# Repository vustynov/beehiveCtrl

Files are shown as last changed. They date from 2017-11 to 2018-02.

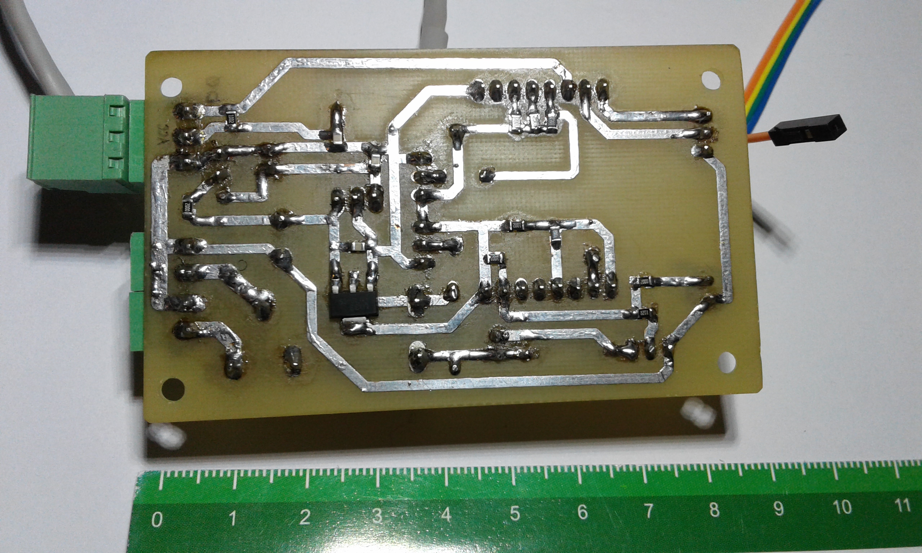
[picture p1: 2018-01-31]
board/BeeTermostat-appearance-bottom.jpg

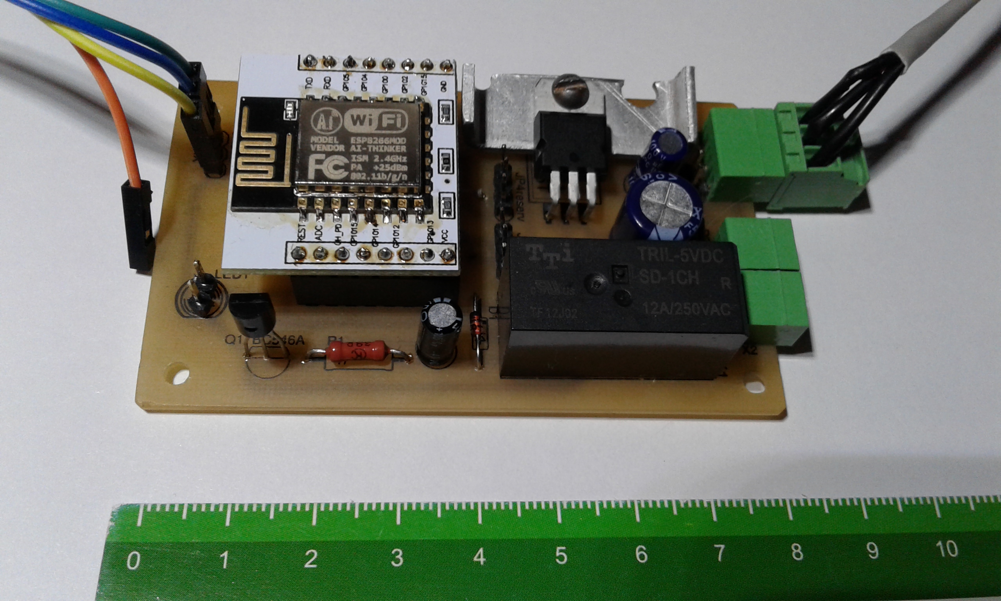
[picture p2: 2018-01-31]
board/BeeTermostat-appearance-top.jpg

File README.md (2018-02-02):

# beehiveCtrl

### Brief
This project can be interesting for amateur beekeeping. The project is designed to monitor the temperature and control the heating of beehives remotely. The device and software can also be used to control temperature control in other projects, such as an incubator.

The device is based on the microcontroller [ESP8266](http://www.esp8266.com) and firmware [NodeMCU](https://en.wikipedia.org/wiki/NodeMCU).

### Features
 * Remote control the temperature in the hive via browser on your computer, smartphone, tablets
 * Remote set the parameters of heater (minimal and maximal temperature)
 * Transfer of the temperature and the current status of the heater to the [thingspeak.com](http://thingspeak.com) every X minutes
 * Builds the [charts](https://thingspeak.com/channels/185299)
 * Once set up, the device can work offline, without internet connection.

### Schems and Circuit board
Directory **board** contains schematic and circuit board of device developed in [EAGLE](https://www.autodesk.com/products/eagle/overview). 
The scheme is very simple. It consists the power regulatots (LM7805 and 1117S33) for the relay coil and microcontroller. To switch on the relay a driver is used the BC546 transistor.

### Source code
Directory **src** contains the source code of the project, wroted on Lua and based on [NodeMCU API](https://nodemcu.readthedocs.io/en/master/).

### How to build
1. Build the board according to the schematic diagram showed on **board/BeeTermostat.sch**
2. Connect *+12-18V* power to *X1* connector on your board without installing the ESP8266 and check the correctness of the voltage at the points of the circuit where the power of the microcontroller must be approached. It should be the "3.3V".
3. Power off your board, install the ESP8266 to the socket on the board, and connect the **JP3** (TX,RX,GND) connector to the computer via USB-TTL adapter. For example, you can use [this device](http://www.instructables.com/id/USB-to-TTL-Converter-PL2303HX/) for that.
4. Power on your board and check the WiFi new access points in you environment. You should discover a new access point with a default name (installed by [Expressif](https://www.espressif.com/) ).
5. Build and download the NodeMCU firmware from the [nodemcu-build.com](https://nodemcu-build.com/) Choose the following modules:
 - DS18B20
 - file
 - GPIO
 - net
 - node
 - 1-wire
 - timer
 - UART
 - WiFi
 - float

6. Install the NodeMCU firmware to microcontroller. Under Linux you can use the [esptool](https://github.com/espressif/esptool) (read this [esp-linux-guide](http://www.whatimade.today/flashing-the-nodemcu-firmware-on-the-esp8266-linux-guide/) for that. Example of install:
```
$ sudo ./esptool-master/esptool.py --port /dev/ttyUSB0 --baud 460800 write_flash --flash_size 32m -fm dio 0x00000 ./nodemcu-master-10-modules-2017-09-25-18-22-58-float.bin
```

7. Install the [ESPlorer](https://esp8266.ru/esplorer/) or some another tools for working with NodeMCU to your computer.
8. Upload the lua scripts from directory **src** to your ESP microcontoller by using the ESPlorer or some another tools.
9. Restart module, find new WiFi access point *beehive* and try to connect to this AP with password *11111111*. You can change *SID* and *password* before in the **src/bc-init.cfg**.
10. If connect is successfull, try to open http://192.168.2.1 in your browser. You sould see the page with configuration of your beehive controller.
11. Try to change the temperature settings and check your heater.

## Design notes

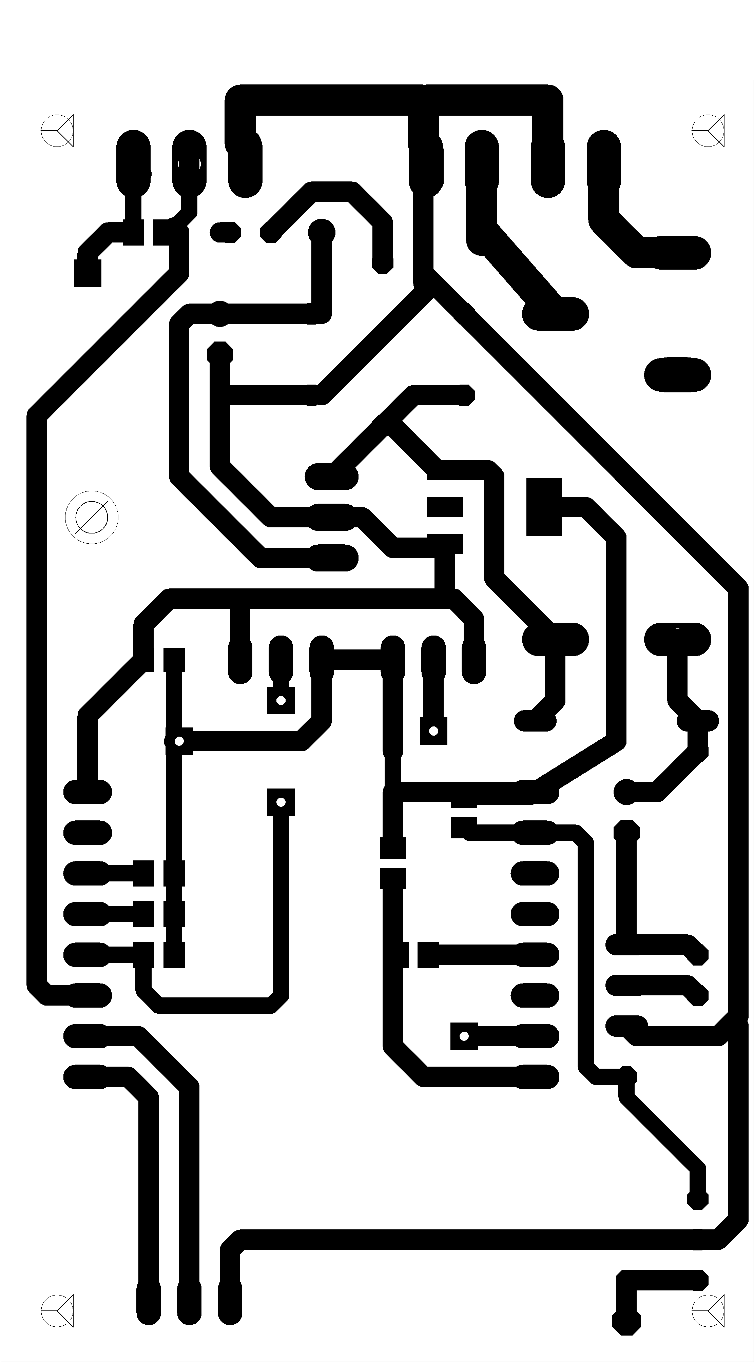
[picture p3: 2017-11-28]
board/beehiveTermostat_bottom_pcb_i.png

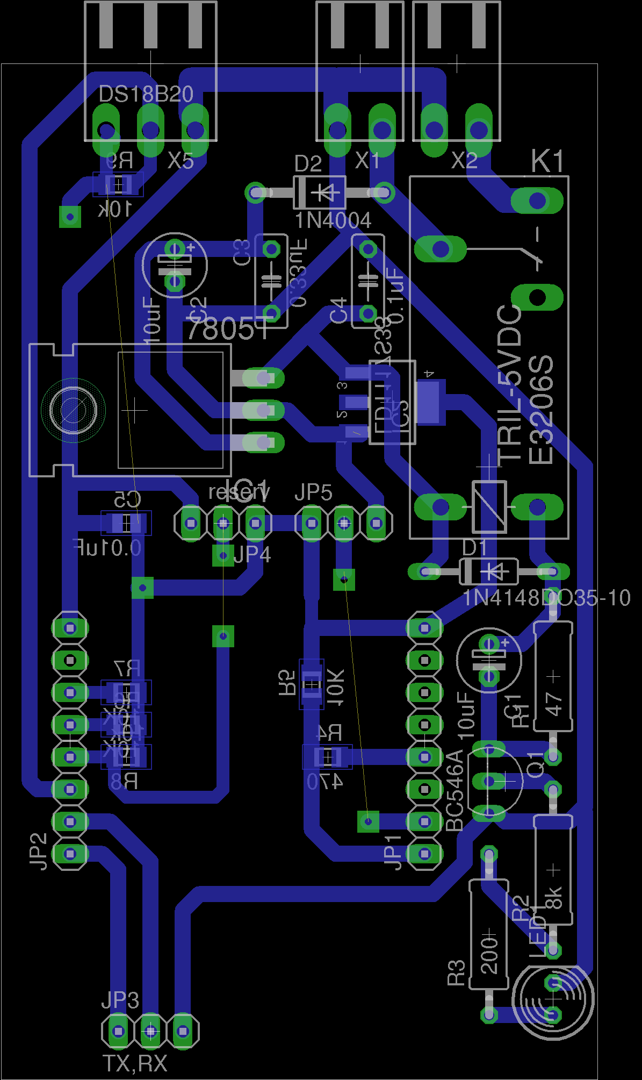
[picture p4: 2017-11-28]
board/beehiveTermostat.png

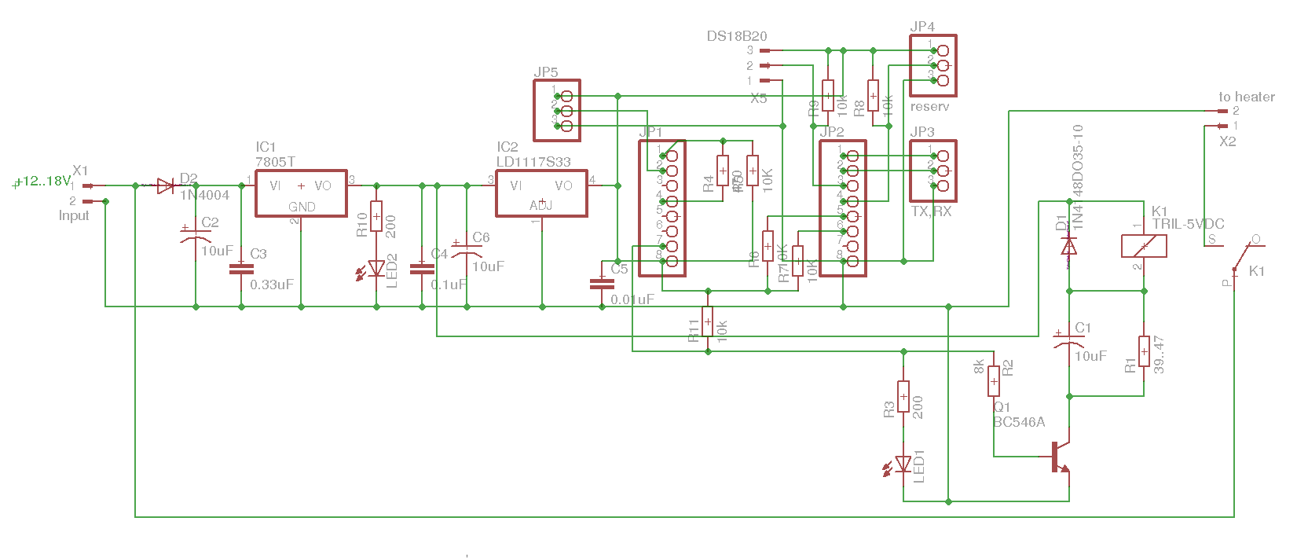
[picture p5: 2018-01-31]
board/BeeTermostat-schem.png

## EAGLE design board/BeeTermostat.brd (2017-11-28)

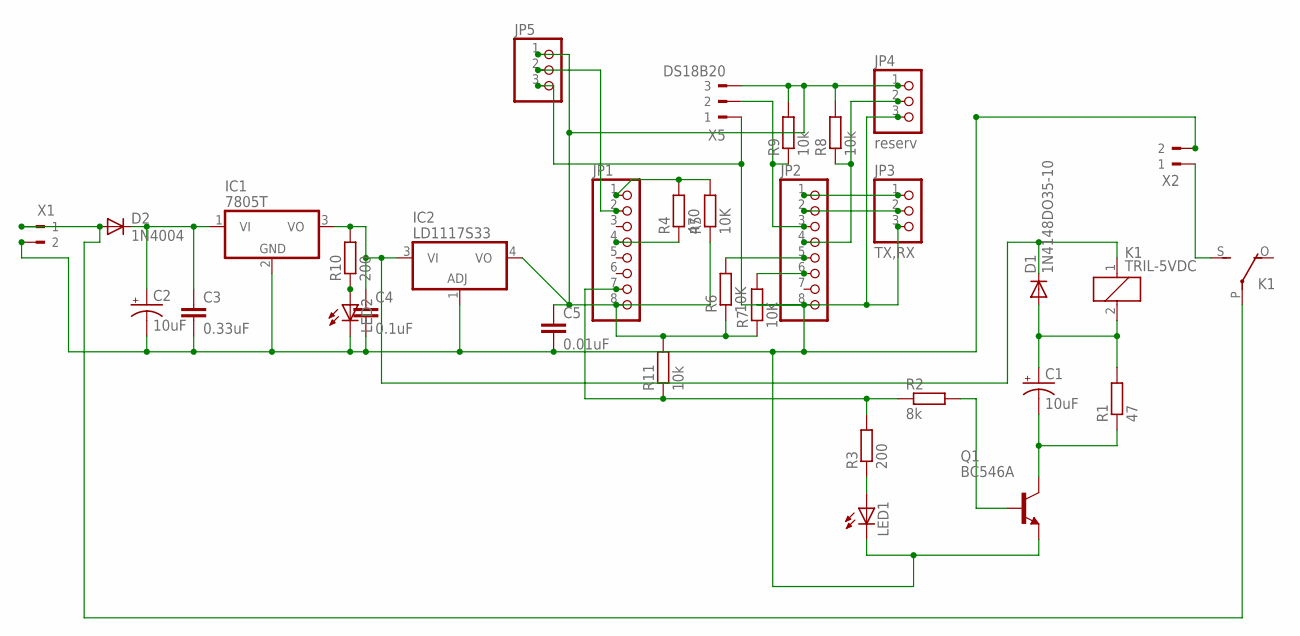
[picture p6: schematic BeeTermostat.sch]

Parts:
C1, C2: 10uF; E2,5-5
C3: 0.33uF; C050-025X075
C4: 0.1uF; C050-025X075
C5: 0.01uF; C0805
D1: 1N4148DO35-10; DO35-10
D2: 1N4004; DO41-10
IC1: 7805T; TO220H
IC2: LD1117S33; SOT223
JP1, JP2: PINHD-1X8; 1X08
JP3: TX,RX; 1X03
JP4: reserv; 1X03
JP5: PINHD-1X3; 1X03
K1: TRIL-5VDC; E3206S
LED1, LED2: LED5MM
Q1: BC546A; TO92-EBC
R1: 47; 0309/12
R2: 8k; 0309/12
R3: 200; 0309/12
R4: 470; M0805
R5, R6, R7: 10K; M0805
R8, R9, R11: 10k; M0805
R10: 200; 0207/10
X1, X2: 90-2
X5: DS18B20; 90-3

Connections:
unnamed: C1.+, D1.A, K1.2, R1.2
unnamed: C1.-, Q1.C, R1.1
unnamed: Q1.B, R2.2
unnamed: JP1.7, R2.1, R3.2, R11.1
unnamed: LED1.A, R3.1
unnamed: C2.+, C3.1, D2.C, IC1.1 (VI)
unnamed: C4.1, D1.C, IC1.3 (VO), IC2.3 (VI), K1.1, R10.2
unnamed: JP2.3, R9.1, X5.2
unnamed: JP2.1, JP3.1
unnamed: K1.S, X2.1
unnamed: JP2.2, JP3.2
unnamed: C2.-, C3.2, C4.2, C5.2, IC1.2 (GND), IC2.1 (ADJ), JP2.8, JP3.3, JP4.3, JP5.3, LED1.K (C), LED2.K (C), Q1.E, X1.2, X2.2, X5.1
unnamed: JP2.5, R6.2
unnamed: JP1.4, R4.1
unnamed: JP1.1, R4.2, R5.2
unnamed: JP2.6, R7.2
unnamed: D2.A, K1.P, X1.1
unnamed: JP2.4, JP4.2, R8.1
unnamed: C5.1, IC2.4 (VO), JP1.8, JP4.1, JP5.1, R5.1, R6.1, R7.1, R8.2, R9.2, R11.2, X5.3
unnamed: JP1.2, JP5.2
unnamed: LED2.A, R10.1

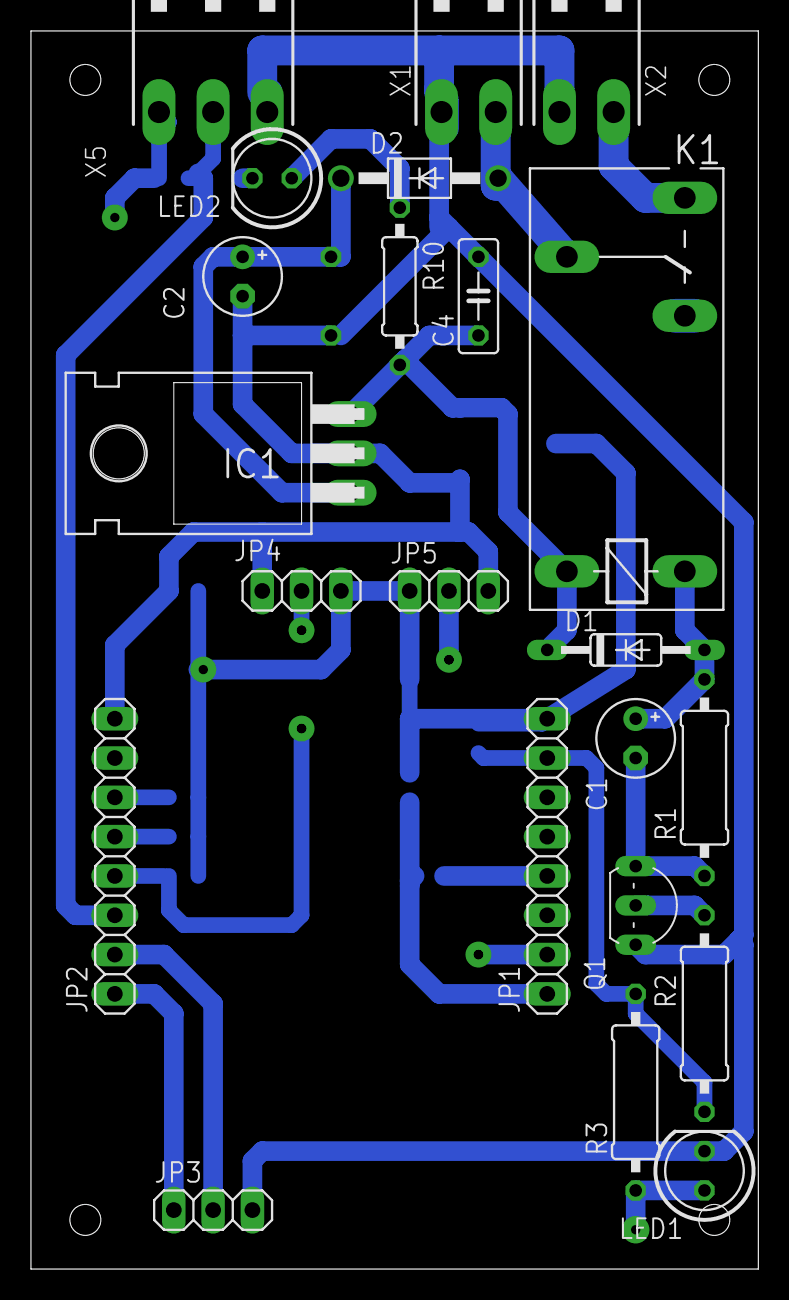
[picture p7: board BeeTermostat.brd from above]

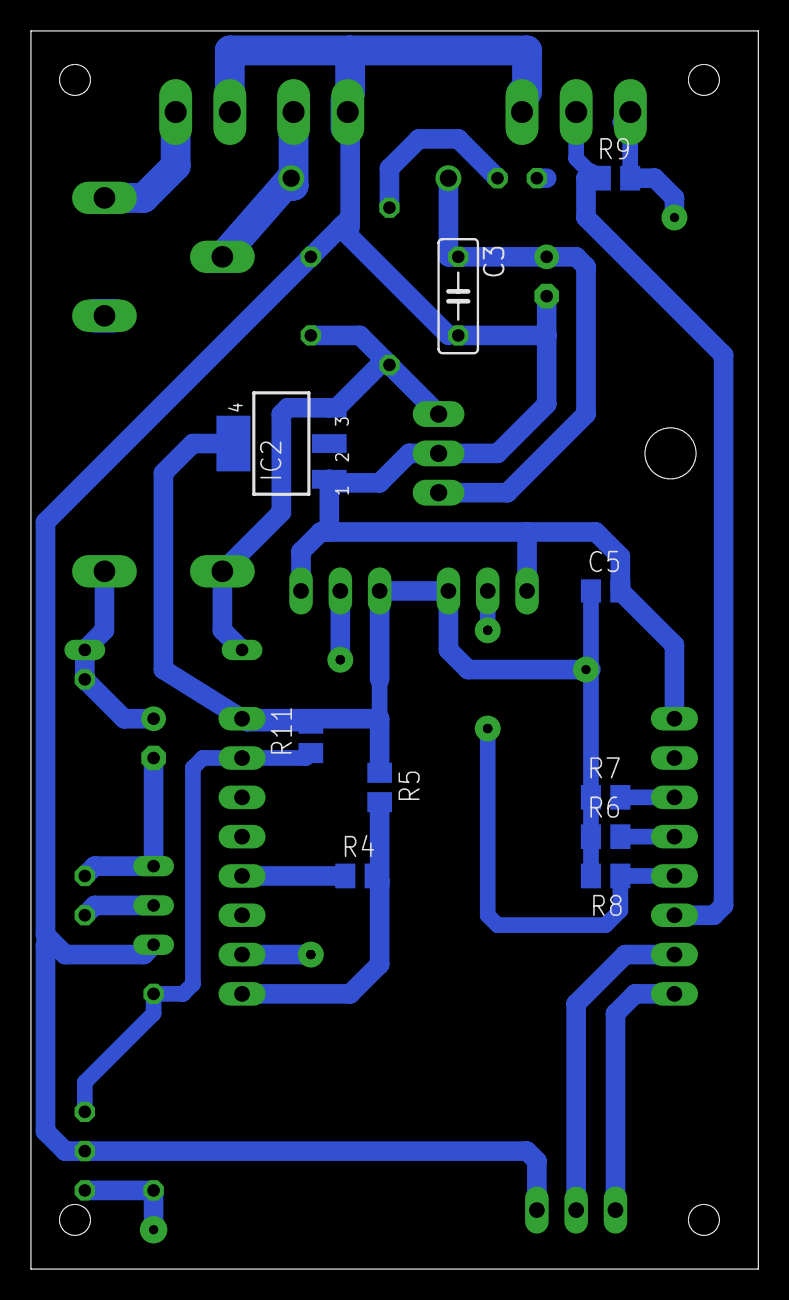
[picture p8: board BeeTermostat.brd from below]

Board: 2 copper layers, 47.0 x 80.0 mm, 32 parts (10 on the bottom side), 21 nets.

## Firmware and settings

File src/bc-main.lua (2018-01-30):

-- bc-main.lua
-- Main application of Beehive Controller.
-- Author: victoru


-- Loading the ds18b20.lua module
ds18b20 = dofile("ds18b20.lc")

GPIO5 = 1
GPIO13 = 7

----------------------------------------------------
-- GPIO pin of temperature sensor (INPUT) 
PIN_TEMP_SENSOR = GPIO5

-- GPIO pin of turning ON and OFF the heater (OUTPUT)
PIN_HEATER = GPIO13

-----------------------------------------------------
-- Setup GPIO pins mode
gpio.mode(PIN_HEATER, gpio.OUTPUT)
gpio.write(PIN_HEATER, gpio.LOW)
gpio.mode(PIN_TEMP_SENSOR, gpio.INPUT)
-----------------------------------------------------

-- configuration from bc-init.cfg
conf = {}

-- global statistic values storage
stor = {}

conf = dofile("bc-conf.lc")

local t_timer = tmr.create()
local heater_stat = false

ds18b20.setup(PIN_TEMP_SENSOR)

t = ds18b20.read()

stor.temp_current = t
stor.temp_switchon = 0
stor.temp_switchoff = 0

local r_timer = tmr.create()

function relay_antistick()
    if gpio.read(PIN_HEATER) == gpio.HIGH then
       gpio.write(PIN_HEATER, gpio.LOW)
       r_timer:alarm( 1000, tmr.ALARM_SINGLE, 
            function() 
                gpio.write(PIN_HEATER, gpio.HIGH)
            end)
    else
       gpio.write(PIN_HEATER, gpio.HIGH)
       r_timer:alarm( 1000, tmr.ALARM_SINGLE, 
            function() 
                gpio.write(PIN_HEATER, gpio.LOW)
            end)
    end
end

local received = 0

--- function sendData sends the data to api.thingspeak.com 
--- after connecting to the site and close connection after 
--- receives some answers
function sendData()
  
  conn=net.createConnection(net.TCP, 0) 

  -- set the on-event functions for connection events
  
  conn:on("receive", function(conn, payload) 
      print(payload) 
      received = 1 
      conn:close() 
      end)


  conn:on("connection", 
    function(conn)
      received = 0 
      print("on-connection: connected, start sending")
      conn:send("GET https://api.thingspeak.com/update?api_key=B6G7CL03OYDOWP9U&field1="..
stor.temp_current.."&field2="..gpio.read(PIN_HEATER).." HTTP/1.0\r\nHost: thingspeak.com\r\nUser-Agent: Mozilla/4.0 (compatible; esp8266 Lua; Windows NT 5.1)\r\nAccept: */*\r\nConnection: close\r\n\r\n") 

    end)

  conn:on("sent", function(conn)
                      
                      print("on-sent: non Closing connection")
                     
                  end)
  conn:on("disconnection", function(conn)
                                print("on-disconnection: Got disconnection...")
                           end)

  -- try to connect
  conn:connect(80,'thingspeak.com')

end



t_timer:alarm( tonumber(conf.read_temp_time), tmr.ALARM_AUTO, 
	function() 
		t=ds18b20.read()
        stor.temp_current = t
        print("t = " .. t )
		if tonumber(t) < tonumber(conf.min_temp) then
            print("p1 PI_HEATER")
			gpio.write(PIN_HEATER, gpio.HIGH)
            stor.temp_switchon = t
            print("p1: " .. gpio.read(PIN_HEATER))
        elseif tonumber(t) < tonumber(conf.max_temp) then
            print("p2 PI_HEATER")
            if (gpio.read(PIN_HEATER) == 0) then
                gpio.write(PIN_HEATER, gpio.HIGH)
                stor.temp_switchon = t
                print("p2: " .. gpio.read(PIN_HEATER))
            end
		end

		if  tonumber(t) > tonumber(conf.max_temp) or t == nil then
            if gpio.read(PIN_HEATER) == gpio.HIGH then
			    gpio.write(PIN_HEATER, gpio.LOW)
                stor.temp_switchoff = t
            -- anti-sticking protection:
            elseif tonumber(t)+2 > tonumber(stor.temp_switchoff) then
                --relay_antistick()
                --stor.temp_switchoff = t
            end
            print("p3: " .. gpio.read(PIN_HEATER))
		end 
	end
)

-- trying the connection to wifi gateway 
-- and send data to the Internet server
tmr.alarm(1, 1000, tmr.ALARM_AUTO, 
     function()
         if wifi.sta.getip()== nil then
         --print("ip=nil")
         else
           tmr.stop(1)
           print("Config done, IP is "..wifi.sta.getip())
           sendData()
     
           tmr.alarm(0, 3000, tmr.ALARM_SEMI, function()
               tmr.stop(0)
--               wifi.sleeptype(wifi.MODEM_SLEEP)
               wifi.sta.disconnect()
--               wifi.setmode(wifi.NULLMODE)
               print("wifi disconnected")         
    end)
  end
end)


station_cfg={}
station_cfg.ssid=tostring(conf.ssid_gw)
station_cfg.pwd=tostring(conf.pass_gw)
station_cfg.auto=false


function wifiStart()
    wifi.setmode(wifi.STATIONAP)
    cfg={}
    cfg.ssid=tostring(conf.ssid_bc)
    cfg.pwd=tostring(conf.pass_bc)
    cfg.channel=6
    wifi.ap.config(cfg)
    cfd ={}
    cfd.ip="192.168.2.1"
    cfd.netmask="255.255.255.0"
    cfd.gateway="192.168.2.1"
    wifi.ap.setip(cfd)
    print("Access Point IP:  " .. wifi.ap.getip())
    print("Access Point MAC: " .. wifi.ap.getmac())
end

wifiStart()



dofile("bc-server.lc")

serverStart("index.html", stor, conf)

-- every 30 minutes
tmr.alarm(3, tonumber(conf.send_data_time), tmr.ALARM_AUTO, 
     function()
--         if  wifi.getmode() == wifi.NULLMODE then
--           tmr.stop(0)
--           print("Connecting to wifi station...")
--           wifi.setmode(wifi.STATIONAP)
--           print(station_cfg.ssid)
--           print(station_cfg.pwd)
           wifi.sta.config( station_cfg )
           wifi.sta.connect()
           tmr.start(1)
--         end
     end
)

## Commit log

2017-11-28 pcb added
    [BeeTermostat.brd, BeeTermostat.sch]
2018-01-30 added new files to project
    [bc-init.cfg]
2018-01-31 update def params
    [bc-init.cfg]
